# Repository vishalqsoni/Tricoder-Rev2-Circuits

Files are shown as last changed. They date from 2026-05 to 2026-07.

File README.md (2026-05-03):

# Star Trek Tricorder Rev2 — PCB & Schematics

> KiCad schematic and PCB layout files for the Star Trek Tricorder Rev2. The hardware is distributed across three boards — Tricorder Main, Tricorder Sensor, and Tricorder LED Array 2 — interconnected via a 20-pin FFC cable.





---

## Table of Contents

- [Board Overview](#board-overview)
- [Tricorder Main](#tricorder-main)
- [Tricorder Sensor](#tricorder-sensor)
- [Tricorder LED Array 2](#tricorder-led-array-2)
- [Interconnect](#interconnect--ffc-cable)
- [Repository Structure](#repository-structure)
- [Tools Used](#tools-used)
- [Related Repositories](#related-repositories)
- [Credits](#credits)

---

## Board Overview

The hardware is split across three dedicated PCBs to keep the design modular and assembly manageable within the compact Tricorder enclosure.

| Board | Role | Files Available |
|---|---|---|
| Tricorder Main | Central controller — ESP32S3, display, audio, touch input | Schematic + Layout |
| Tricorder Sensor | Environmental sensing, power monitoring, LED array 1 | Layout only |
| Tricorder LED Array 2 | Secondary WS2812B LED array | Schematic + Layout |

All boards are KiCad projects and communicate over a shared **I²C bus** via a **20-pin 1mm pitch FFC cable**.

---

## Tricorder Main

The Main PCB is the central control unit built around the **Seeed Studio XIAO ESP32S3**. It sits directly below the TFT display and coordinates all subsystems.

**Files:** Schematic + Layout

### Interfaces

| Interface | Protocol | Connected To |
|---|---|---|
| TFT Display (ST7735) | SPI (MOSI, SCK, CS, DC, RST) | ST7735 1.8" TFT |
| Audio Module (JQ6500) | UART (TX/RX) | JQ6500 |
| GPIO Expander (MCP23008) | I²C (SDA/SCL) | TTP223 touch inputs ×6 |
| LED Array — Primary | Single-wire (WS2812B protocol) | WS2812B LEDs |
| FFC Connector | 20-pin, 1mm pitch | Tricorder Sensor board |

### Key ICs

| IC / Module | Function |
|---|---|
| Seeed Studio XIAO ESP32S3 | Main microcontroller |
| MCP23008 | I²C GPIO expander for touch input routing |
| JQ6500 | UART audio playback module |
| TTP223 ×6 | Capacitive touch sensors |
| WS2812B (2020) | Addressable RGB LEDs — primary array |

---

## Tricorder Sensor

The Sensor Panel contains all environmental sensing and power monitoring components, along with LED Array 1. It connects to the Main PCB entirely over the FFC cable.

**Files:** Layout only

### Interfaces

| Interface | Protocol | Connected To |
|---|---|---|
| Environmental Sensor (BME280) | I²C | Shared I²C bus |
| Power Monitor (INA219) | I²C | Shared I²C bus |
| LED Array 1 | Single-wire (WS2812B protocol) | WS2812B LEDs |
| FFC Connector | 20-pin, 1mm pitch | Tricorder Main board |

### Key ICs

| IC / Module | Function |
|---|---|
| DFRobot BME280 | Temperature, pressure, and altitude sensing |
| INA219 | Voltage, current, and power monitoring |
| WS2812B (2020) | Addressable RGB LEDs — array 1 |

---

## Tricorder LED Array 2

A dedicated board for the secondary WS2812B LED array.

**Files:** Schematic + Layout

### Specifications

| Parameter | Value |
|---|---|
| PCB Material | FR4 |
| Board Thickness | 0.6 mm |

### Key IC

| IC / Module | Function |
|---|---|
| WS2812B (2020) | Addressable RGB LEDs — array 2 |

---

## Interconnect — FFC Cable

All boards communicate over a **20-pin, 1mm pitch FFC cable**, which carries:

| Signal Group | Lines |
|---|---|
| Power | VCC, GND |
| I²C Bus | SDA, SCL |
| LED Control | WS2812B data line |
| Miscellaneous | Additional control and status signals |

Using FFC keeps internal wiring clean, reduces assembly complexity, and allows each board to be removed or replaced independently.

---

## Repository Structure

```
tricorder-rev2-circuits/
│
├── tricorder-main/
│   ├── tricorder-main.kicad_pro
│   ├── tricorder-main.kicad_sch
│   ├── tricorder-main.kicad_pcb
│   └── gerbers/
│
├── tricorder-sensor/
│   ├── tricorder-sensor.kicad_pro
│   ├── tricorder-sensor.kicad_pcb
│   └── gerbers/
│
├── tricorder-led-array-2/
│   ├── tricorder-led-array-2.kicad_pro
│   ├── tricorder-led-array-2.kicad_sch
│   ├── tricorder-led-array-2.kicad_pcb
│   └── gerbers/
│
└── docs/
    └── block-diagram.png
```

---

## Tools Used

| Tool | Purpose |
|---|---|
| [KiCad](https://www.kicad.org/) | Schematic capture and PCB layout |

---

## Related Repositories

| Repository | Contents |
|---|---|
| [Tricorder Rev2 — Firmware](https://github.com/vishalqsoni/Tricoder-Rev2/tree/main) | Arduino firmware, UI, sensors, animations |
| [Tricorder Rev2 — 3D Models](#) | Enclosure and mechanical files |

---

## Credits

- **PCB Design & Hardware** — [Vishal Soni](https://github.com/vishalqsoni)
- **3D Printing** — [JustWay](https://justway3d.com)
- **Firmware**- [Vishal Soni](https://github.com/vishalqsoni)

---

## License

MIT License — see [LICENSE](LICENSE) for details.

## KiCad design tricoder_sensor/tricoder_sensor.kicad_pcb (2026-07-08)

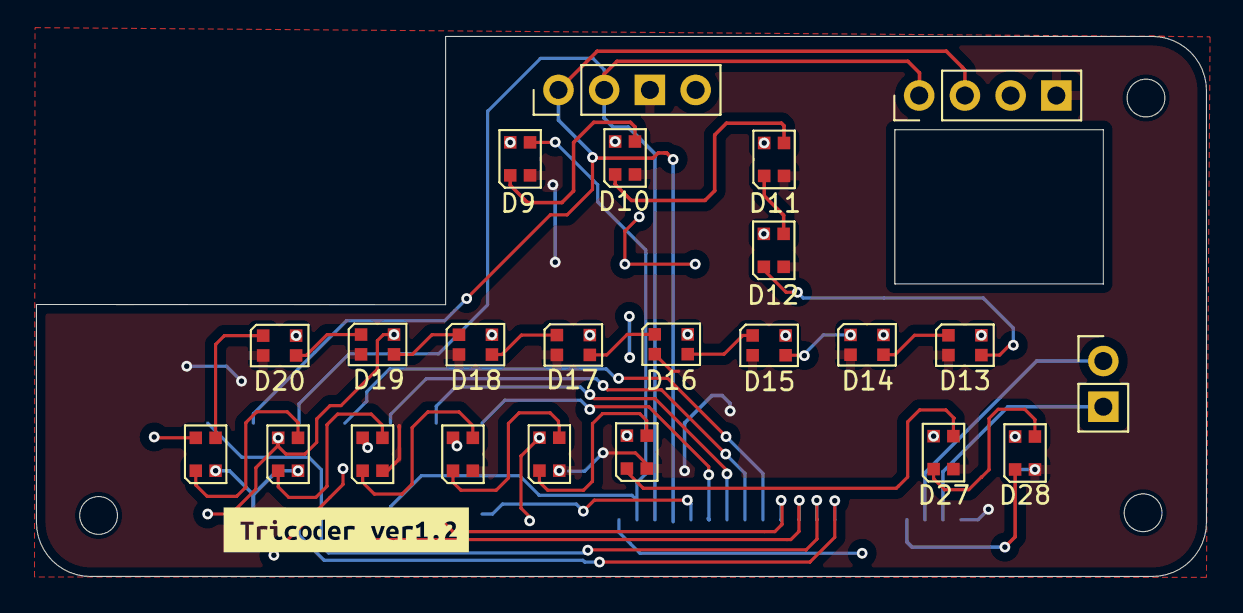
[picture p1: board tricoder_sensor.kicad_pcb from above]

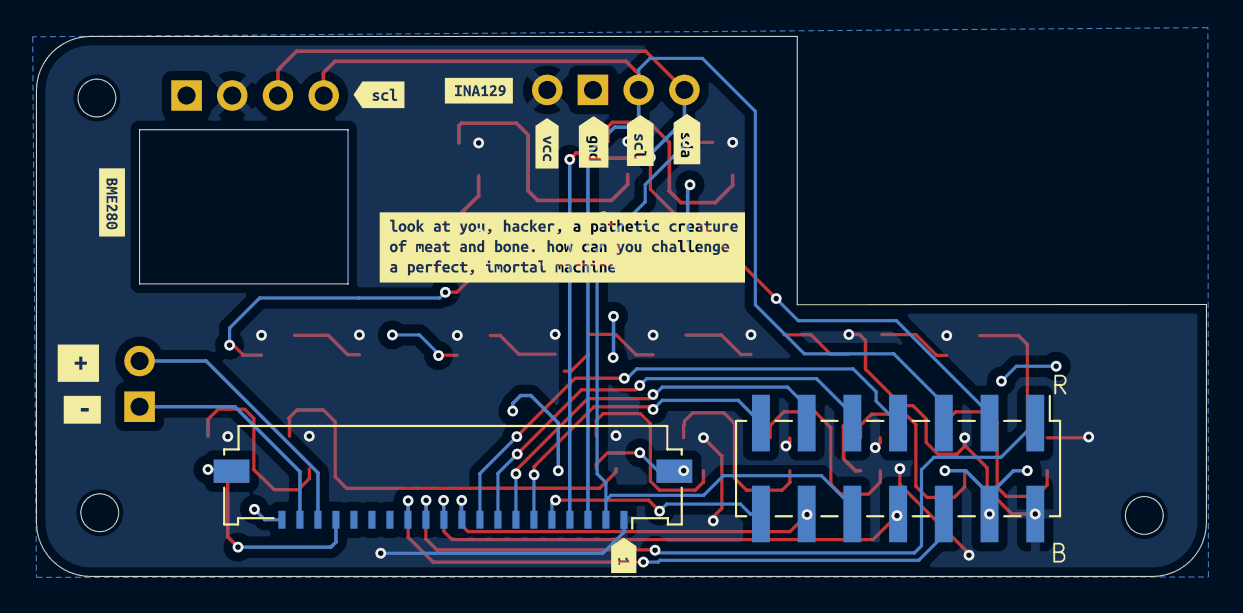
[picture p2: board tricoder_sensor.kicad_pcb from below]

Board: 2 copper layers, 65.0 x 30.0 mm, 32 parts (11 on the bottom side), 2 nets.

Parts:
D1, D1#2, D1#3, D1#4, D1#5, D1#6, D1#7, D1#8, D1#9, D1#10, D13, D14, D15, D16, D17, D18, D19, D20, D27, D28: WS2812B-2020; LED_WS2812B-2020_PLCC4_2.0x2.0mm
kibuzzard-69B7CB67: G***; kibuzzard-69B7CB67
kibuzzard-69B7CB86: G***; kibuzzard-69B7CB86
kibuzzard-69B7CBEE: G***; kibuzzard-69B7CBEE
kibuzzard-69B7CBF3: G***; kibuzzard-69B7CBF3
kibuzzard-69B7CBF9: G***; kibuzzard-69B7CBF9
kibuzzard-69B7CC2E: G***; kibuzzard-69B7CC2E
kibuzzard-69B7CDD1: G***; kibuzzard-69B7CDD1
kibuzzard-69B7CE0B: G***; kibuzzard-69B7CE0B
kibuzzard-69B8F494: G***; kibuzzard-69B8F494
kibuzzard-69B90B5B: G***; kibuzzard-69B90B5B
kibuzzard-69B90B55: G***; kibuzzard-69B90B55
kibuzzard-69B957A1: G***; kibuzzard-69B957A1

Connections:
/GND: D1.2 (VSS), D1#2.2 (VSS), D1#3.2 (VSS), D1#4.2 (VSS), D1#5.2 (VSS), D1#6.2 (VSS), D1#7.2 (VSS), D1#8.2 (VSS), D1#9.2 (VSS), D1#10.2 (VSS), D13.2 (VSS), D14.2 (VSS), D15.2 (VSS), D16.2 (VSS), D17.2 (VSS), D18.2 (VSS), D19.2 (VSS), D20.2 (VSS), D27.2 (VSS), D28.2 (VSS)
/VCC: D1.4 (VDD), D1#2.4 (VDD), D1#3.4 (VDD), D1#4.4 (VDD), D1#5.4 (VDD), D1#6.4 (VDD), D1#7.4 (VDD), D1#8.4 (VDD), D1#9.4 (VDD), D1#10.4 (VDD), D13.4 (VDD), D14.4 (VDD), D15.4 (VDD), D16.4 (VDD), D17.4 (VDD), D18.4 (VDD), D19.4 (VDD), D20.4 (VDD), D27.4 (VDD), D28.4 (VDD)

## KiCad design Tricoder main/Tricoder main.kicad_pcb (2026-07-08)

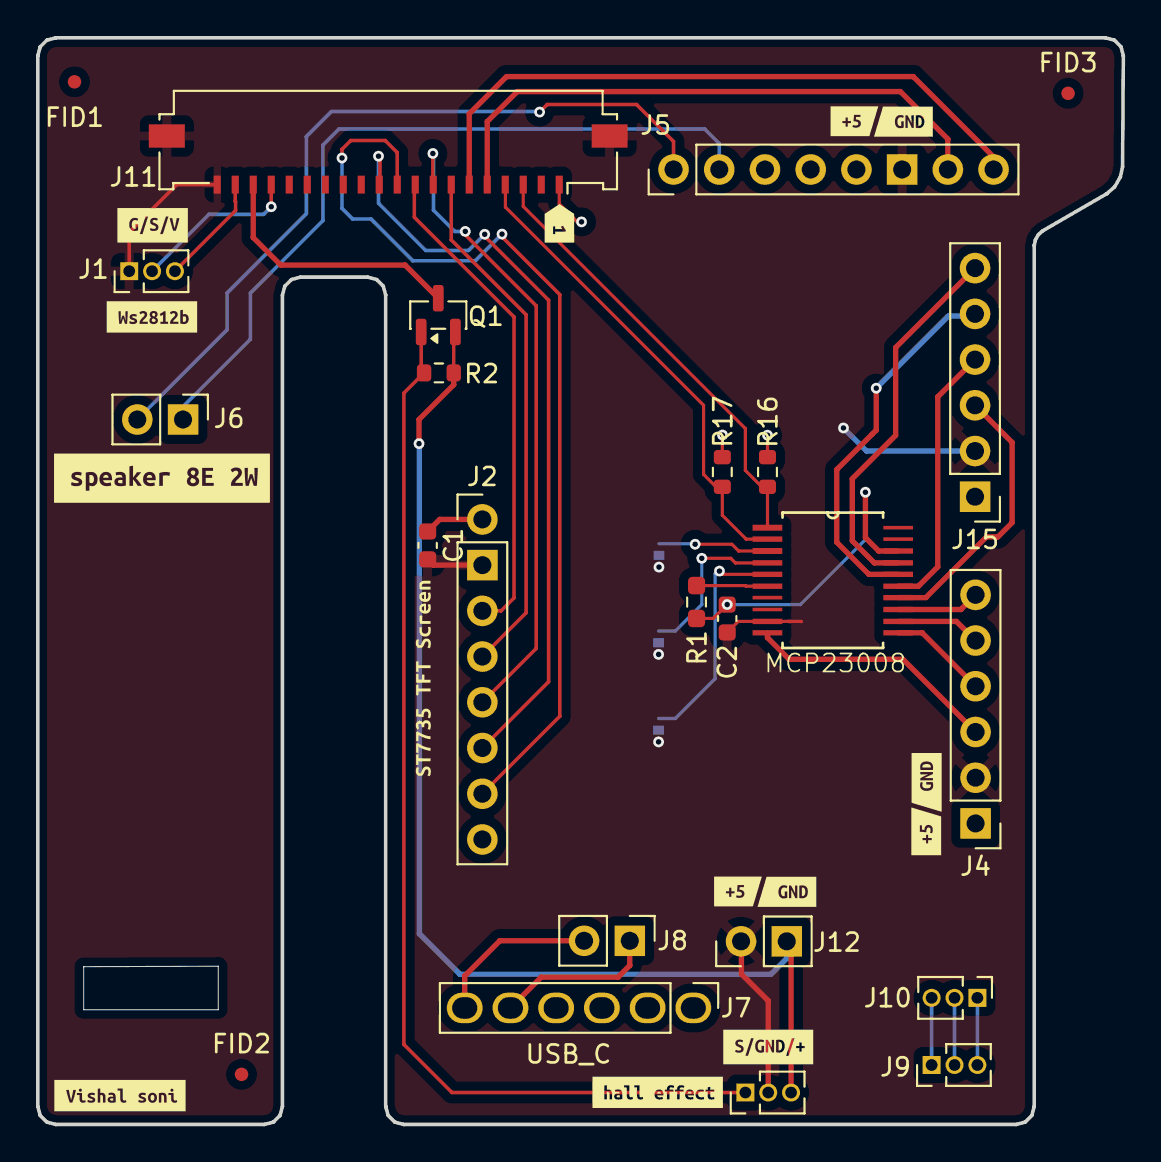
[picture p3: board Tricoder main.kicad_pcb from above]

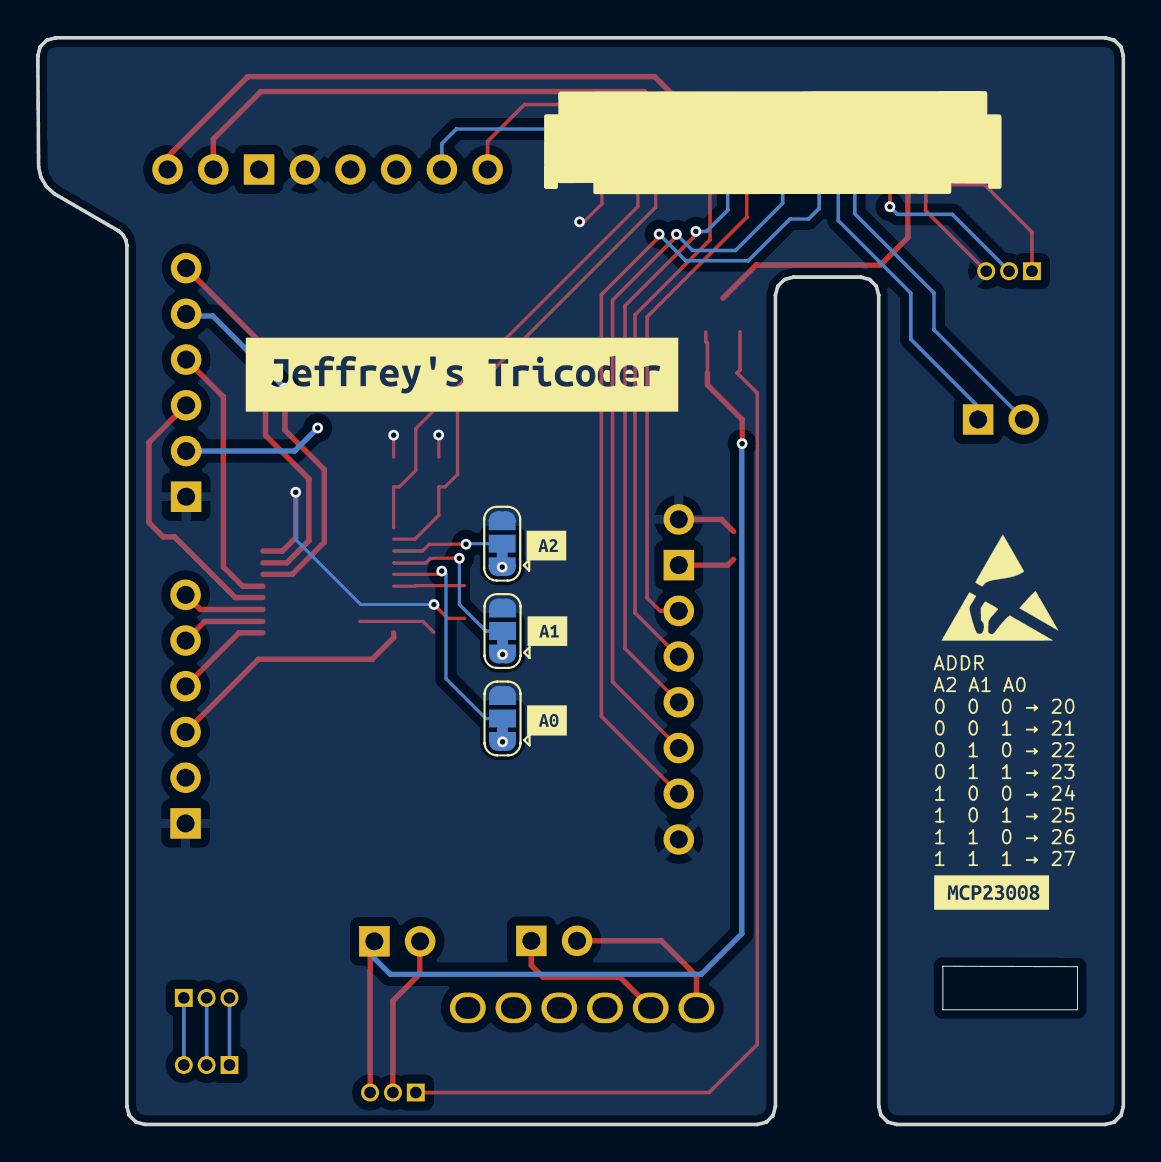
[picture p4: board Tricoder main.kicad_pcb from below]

Board: 2 copper layers, 60.3 x 60.4 mm, 46 parts (8 on the bottom side), 34 nets.

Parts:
C1, C2: 0.1uF; C_0603_1608Metric
FID1, FID2, FID3: Fiducial; Fiducial_0.75mm_Mask1.5mm
J1: WS2812B; PinHeader_1x03_P1.27mm_Vertical
J2: TFT_Screen; PinHeader_1x08_P2.54mm_Vertical
J4: touch_p1; PinHeader_1x06_P2.54mm_Vertical
J5: JQ6500; PinHeader_1x08_P2.54mm_Vertical
J6: speaker; PinHeader_1x02_P2.54mm_Vertical
J7: usbC; PinHeader_1x06_P2.54mm_Vertical
J8: battery_charging; PinHeader_1x02_P2.54mm_Vertical
J9, J10: charging indicator; PinHeader_1x03_P1.27mm_Vertical
J11: ffc-ffp; Molex_200528-0200_1x20-1MP_P1.00mm_Horizontal
J12: battery_output; PinHeader_1x02_P2.54mm_Vertical
J13: Hall Effect; PinHeader_1x03_P1.27mm_Vertical
J15: touch_p2; PinHeader_1x06_P2.54mm_Vertical
JP7: U1_A0; SolderJumper-3_P1.3mm_Bridged12_RoundedPad1.0x1.5mm
JP9: U1_A1; SolderJumper-3_P1.3mm_Bridged12_RoundedPad1.0x1.5mm
JP12: U1_A2; SolderJumper-3_P1.3mm_Bridged12_RoundedPad1.0x1.5mm
Q1: AO3407A; SOT-23
R1: 10K; R_0603_1608Metric_Pad0.98x0.95mm_HandSolder
R2: 10k; R_0603_1608Metric
R16, R17: 4K7; R_0603_1608Metric
U2: MCP23008-xSO; SOP65P780X200-20N
kibuzzard-69B1E323: G***; kibuzzard-69B1E323
kibuzzard-69B9A5BA: G***; kibuzzard-69B9A5BA
kibuzzard-69B9A5CD: G***; kibuzzard-69B9A5CD
kibuzzard-69B9A650: G***; kibuzzard-69B9A650
kibuzzard-69B996E9, kibuzzard-69B996E9#2, kibuzzard-69B996E9#3: G***; kibuzzard-69B996E9
kibuzzard-69B99707, kibuzzard-69B99707#2, kibuzzard-69B99707#3: G***; kibuzzard-69B99707
kibuzzard-69BA1AA8: G***; kibuzzard-69BA1AA8
kibuzzard-69BA1B42: G***; kibuzzard-69BA1B42
kibuzzard-69BA2D04: G***; kibuzzard-69BA2D04
kibuzzard-69BA573E: G***; kibuzzard-69BA573E
kibuzzard-69BA5641: G***; kibuzzard-69BA5641
kibuzzard-69BA5720: G***; kibuzzard-69BA5720
kibuzzard-69BA5749: G***; kibuzzard-69BA5749
kibuzzard-69BA5815: G***; kibuzzard-69BA5815
kibuzzard-69BA5933: G***; kibuzzard-69BA5933

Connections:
+5V: C1.1, C2.1, J1.3, J2.1, J2.8, J4.1, J5.5, J11.1, J11.19, J15.1, JP7.3 (B), JP9.3 (B), JP12.3 (B), R1.2, R16.1, R17.1, U2.18 (VDD)
/Battery: J12.2, J13.3, Q1.2 (S), R2.2
/CS_TFT: J2.3, J11.9
/DC_TFT: J2.5, J11.8
/Hall_Effect: J13.1, Q1.1 (G), R2.1
/INA219+: J11.18, Q1.3 (D)
/JQ6500_RX: J5.8, J11.6
/JQ6500_TX: J5.7, J11.5
/MOSI/SDA_TFT: J2.6, J11.11
/RESET_TFT: J2.4, J11.7
/SCK_TFT: J2.7, J11.10
/SCL: J11.3, R16.2, U2.1 (SCL)
/SDA: J11.4, R17.2, U2.2 (SDA)
/U1_0: J4.3, U2.10 (GP0)
/U1_1: J4.4, U2.11 (GP1)
/U1_2: J4.5, U2.12 (GP2)
/U1_3: J4.6, U2.13 (GP3)
/U1_4: J15.3, U2.14 (GP4)
/U1_5: J15.4, U2.15 (GP5)
/U1_6: J15.5, U2.16 (GP6)
/U1_7: J15.6, U2.17 (GP7)
/U1_A0: JP7.2 (C), U2.5 (A0)
/U1_A1: JP9.2 (C), U2.4 (A1)
/U1_A2: JP12.2 (C), U2.3 (A2)
/WS2812B: J1.2, J11.17
GND: C1.2, C2.2, J1.1, J2.2, J4.2, J5.6, J11.20, J11.21, J11.22, J12.1, J13.2, J15.2, JP7.1 (A), JP9.1 (A), JP12.1 (A), U2.9 (VSS)
unnamed: J5.1, J6.2
unnamed: J5.2, J6.1
unnamed: J7.5, J8.1
unnamed: J7.6, J8.2
unnamed: J9.3, J10.1
unnamed: J9.2, J10.2
unnamed: J9.1, J10.3
unnamed: R1.1, U2.6 (~RESET)

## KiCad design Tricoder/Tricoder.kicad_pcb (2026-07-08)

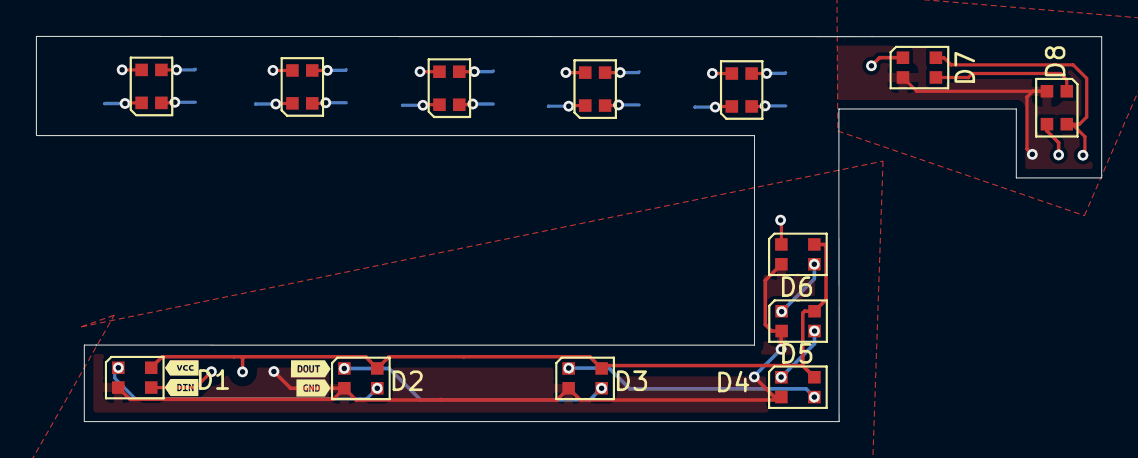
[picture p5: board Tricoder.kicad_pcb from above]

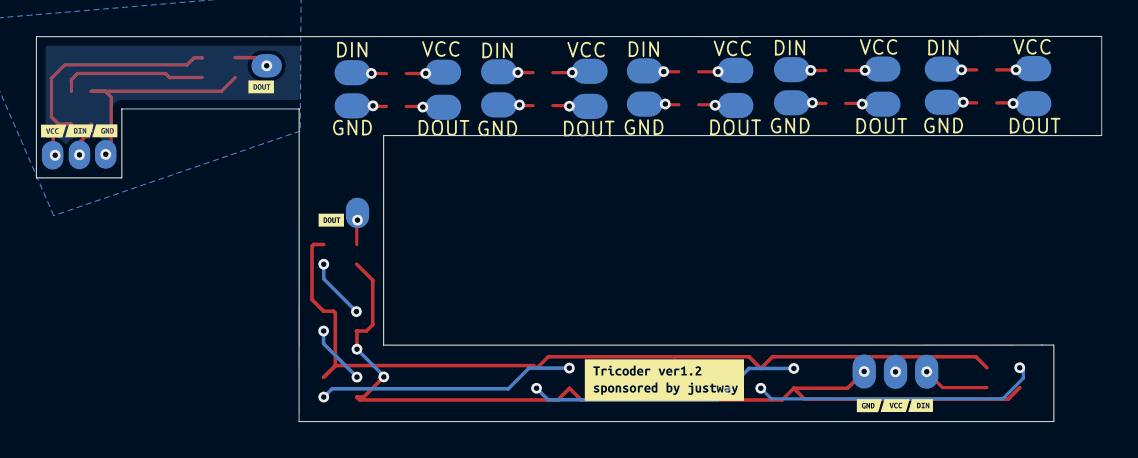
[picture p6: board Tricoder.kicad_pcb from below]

Board: 2 copper layers, 59.2 x 21.4 mm, 26 parts (9 on the bottom side), 9 nets.

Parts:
D1, D1#2, D1#3, D1#4, D1#5, D1#6, D2, D3, D4, D5, D6, D7, D8: WS2812B-2020; LED_WS2812B-2020_PLCC4_2.0x2.0mm
kibuzzard-69B3FD8B: G***; kibuzzard-69B3FD8B
kibuzzard-69B3FDA1: G***; kibuzzard-69B3FDA1
kibuzzard-69B452CC: G***; kibuzzard-69B452CC
kibuzzard-69B452F6, kibuzzard-69B452F6#2: G***; kibuzzard-69B452F6
kibuzzard-69B455A9: G***; kibuzzard-69B455A9
kibuzzard-69B4041F: G***; kibuzzard-69B4041F
kibuzzard-69B4043D: G***; kibuzzard-69B4043D
kibuzzard-69B4529B: G***; kibuzzard-69B4529B
kibuzzard-69B5913D: G***; kibuzzard-69B5913D
kibuzzard-69B45234: G***; kibuzzard-69B45234
kibuzzard-69B59132: G***; kibuzzard-69B59132
kibuzzard-69B59139: G***; kibuzzard-69B59139

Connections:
/DIN: D1#4.3 (DIN), D8.3 (DIN)
/DOUT: D6.1 (DOUT), D7.1 (DOUT)
/GND: D1#4.2 (VSS), D2.2 (VSS), D3.2 (VSS), D4.2 (VSS), D5.2 (VSS), D6.2 (VSS), D7.2 (VSS), D8.2 (VSS)
/VCC: D1#4.4 (VDD), D2.4 (VDD), D3.4 (VDD), D4.4 (VDD), D5.4 (VDD), D6.4 (VDD), D8.4 (VDD)
unnamed: D1#4.1 (DOUT), D2.3 (DIN)
unnamed: D2.1 (DOUT), D3.3 (DIN)
unnamed: D3.1 (DOUT), D4.3 (DIN)
unnamed: D4.1 (DOUT), D5.3 (DIN)
unnamed: D5.1 (DOUT), D6.3 (DIN)
